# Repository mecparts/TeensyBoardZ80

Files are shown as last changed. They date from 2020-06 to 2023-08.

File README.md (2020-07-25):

# Teensy Board/Z80 - A Teensy4.0 based ZCPR3.3/ZSDOS Z80 computer

The Teensy Board/Z80 is a
[Teensy 4.0](https://www.pjrc.com/store/teensy40.html) computer running a
ZCPR3.3/ZSDOS variant of [RunCPM](https://github.com/MockbaTheBorg/RunCPM).

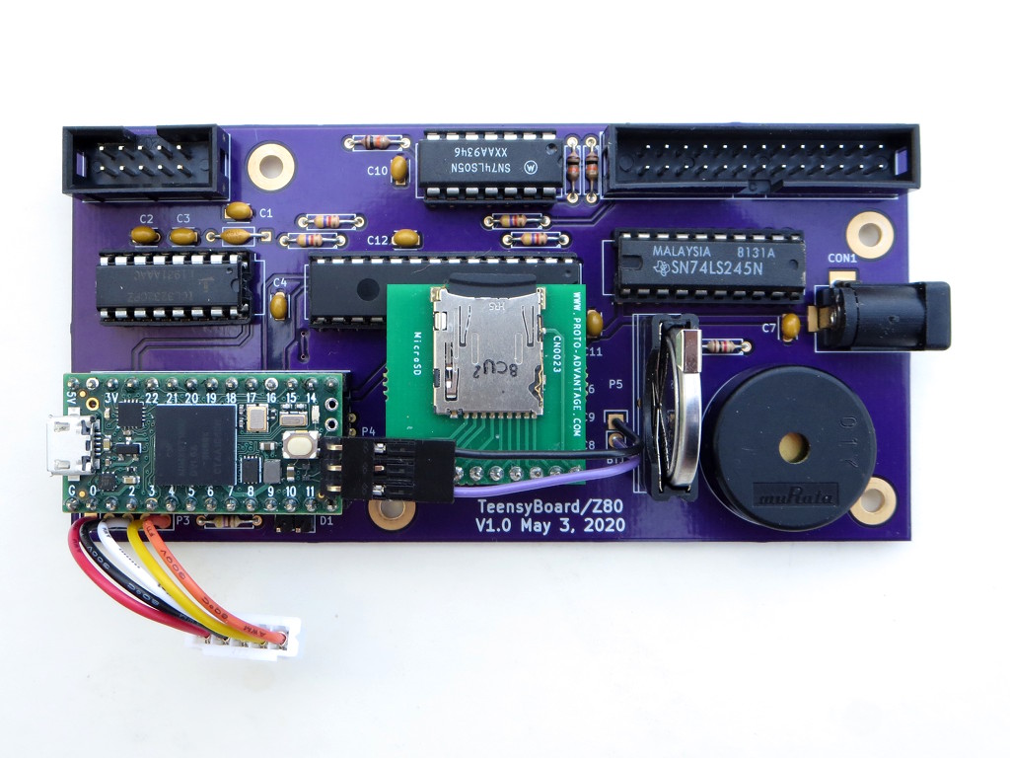
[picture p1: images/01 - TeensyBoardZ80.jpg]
Teensy Board/Z80 The Teensy Board/Z80


Features:
* 100-140MHz equivalent Z80 (RunCPM doesn't emulate cycle times - it just goes *fast*).
* SDIO connected uSD card (about 2.5x faster than SPI) with a standard FAT file system.
* ANSI colour terminal emulator with [GSX](https://github.com/mecparts/pigfx)
graphics support. Runs on a first generation Raspberry Pi, so HDMI video
and USB keyboards are natively supported.
* Battery backed up real time clock.
* Centronics compatible parallel port (DB-25F).
* RS-232 serial port (DE-9M) with RTS/CTS hardware flow control.

## Hardware

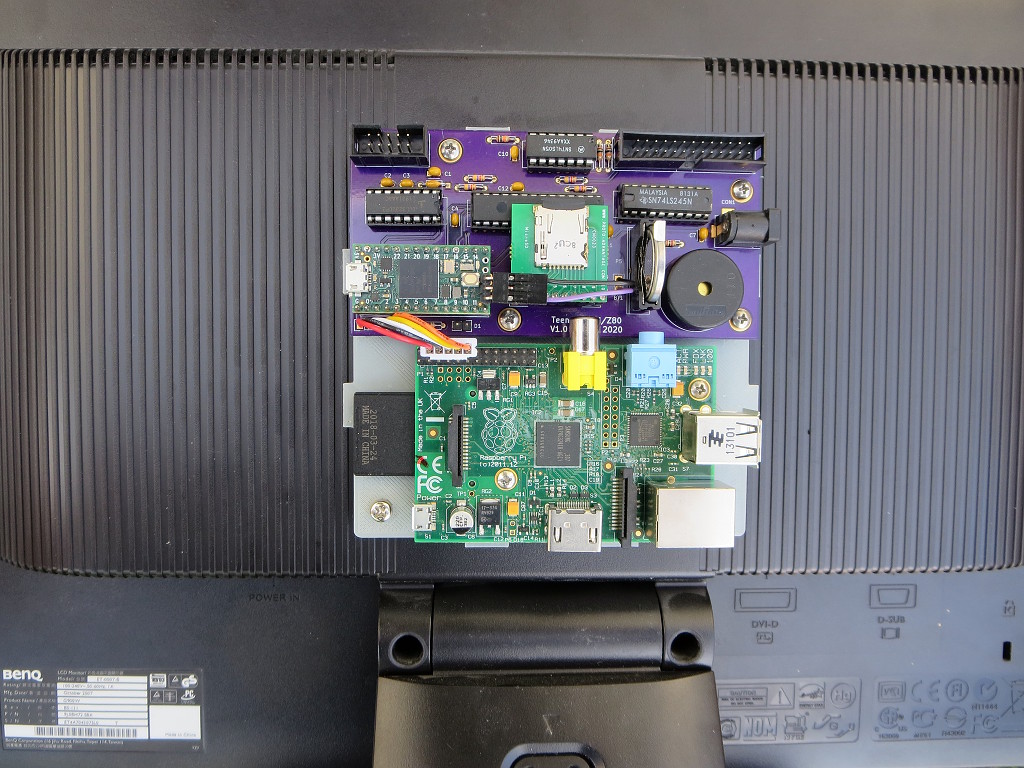
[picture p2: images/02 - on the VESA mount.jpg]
VESA mount The Teensy Board/Z80 and the Raspberry Pi on the VESA mount


The PCB for the Teensy Board/Z80 fits on a VESA mount along with an
original Raspberry Pi 1 B (rev 2). The Pi is the ANSI console used by
the Teensy Board/Z80.

Along with the internal connection to the ANSI terminal, the Teensy Board/Z80
has two vintage I/O ports: an RS-232 port with a DE-9 connector, with
RTS/CTS handshaking, and a Centronics parallel port. The RS-232 port is
the TTY: device in the Teensy Board/Z80's BIOS. The parallel port is,
quite naturally, the LPT: device.

In my setup, the RS-232 port is hooked up to a
[Retro WiFi modem](https://github.com/mecparts/RetroWiFiModem), complete
with Hayes Smartmodem style LED indicators.

The Teensy 4's real time clock is used in ZSDOS to support file timestamps
via the normal ZSDOS calls. A CR2032 coin cell provides the battery back up.

## Case

The Ampro Little Board/Z80 mounted on the bottom of a 5.25" floppy drive.
The Teensy Board/Z80 mounts on a VESA mount on the back on an LCD monitor.

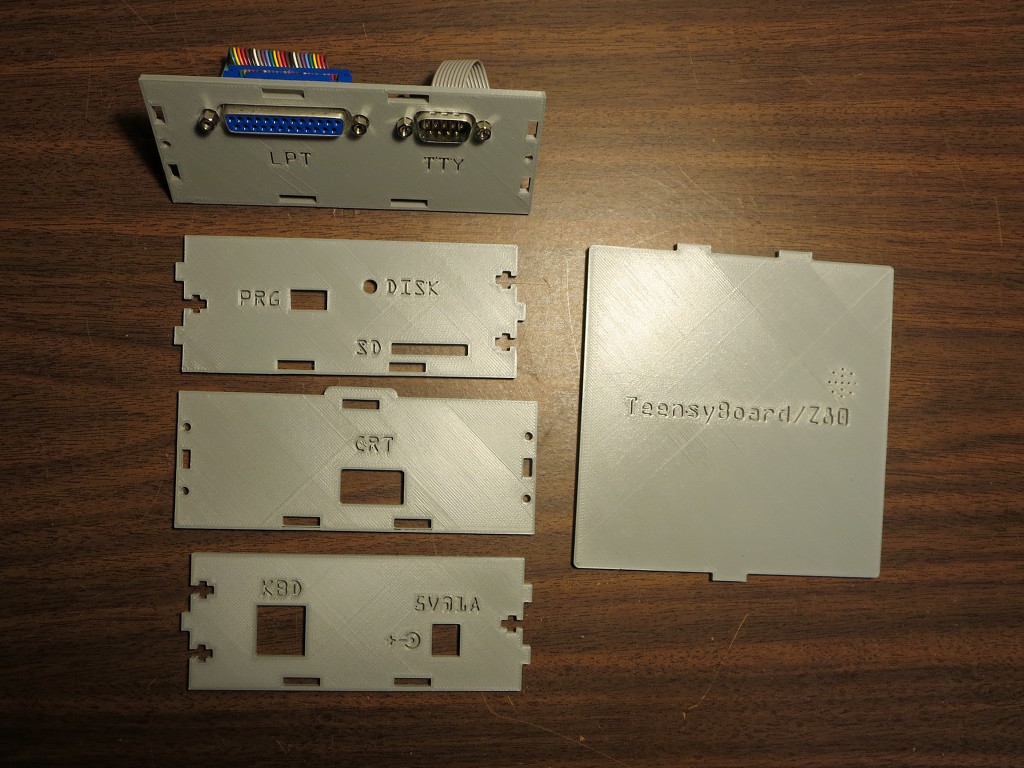
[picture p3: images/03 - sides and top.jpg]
Case bits and pieces The case bits and pieces


The case was designed in OpenSCAD. Although it's 3D printed, it's designed
like a laser cut case, with separate sides, top and bottom. This allowed
a quicker "getting it to fit" cycle than if the bottom and sides had been
printed as one piece; this way, individual sides could by reprinted.

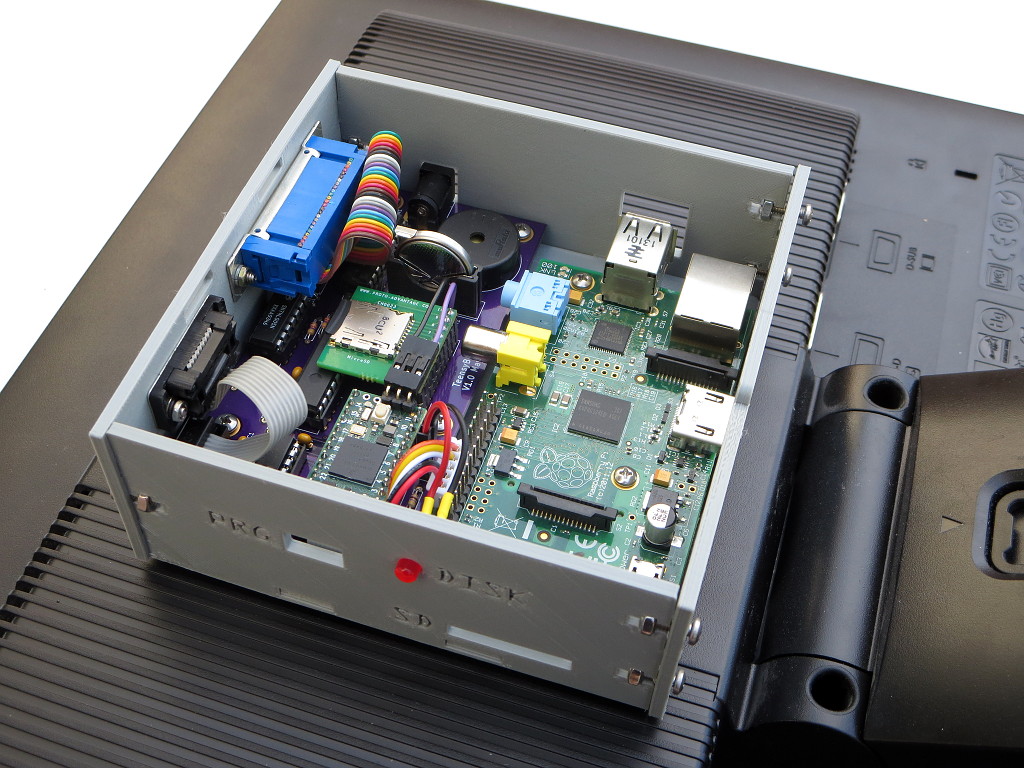
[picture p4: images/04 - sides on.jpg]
Sides on


The base is printed with integrated standoffs. The hole are sized to accept
a #4/40 tap so that no nuts are required. It took a bit of care to get the
holes tapped without snapping the standoffs. Both the Teensy Board PCB and
the Raspberry Pi will take 1/2" 4/40 screws in lieu of the M2.5s normally
specified for the Pi.

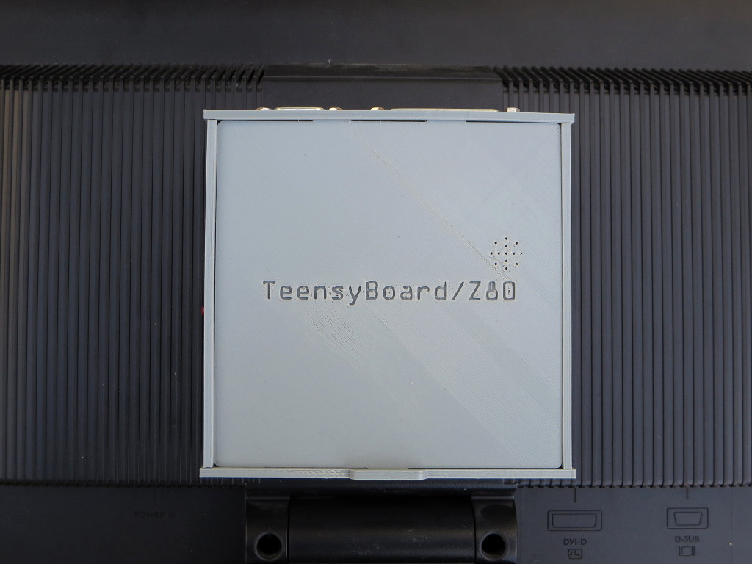
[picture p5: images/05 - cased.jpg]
Completed case The completed case


The sides bolt together with 3/8" #4-40 screws. The filament was plain old
PLA.

## Software

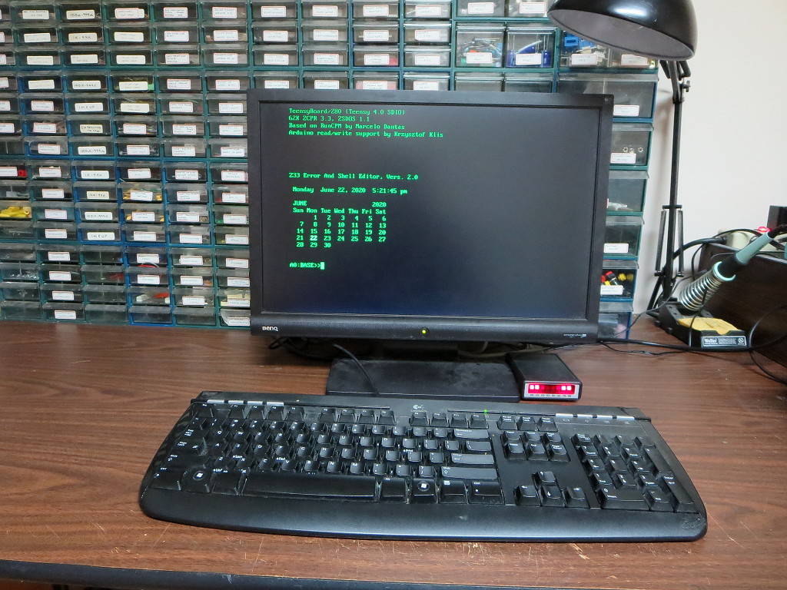
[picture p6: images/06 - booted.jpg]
Booted


When I bought my first Teensy 4.0 last autumn, I'd thought about looking
around for a Z80 emulator written in C and implementing a BIOS in Z80
assembler that would talk to the Teensy hardware... somehow. Luckily, I
came across [RunCPM](https://github.com/MockbaTheBorg/RunCPM) first. It
had already solved the problem of communicating with the Teensy
hardware, and had done it with a FAT file system. I stopped looking! I
had the first system up and running within an hour of getting home with
the Teensy.

Over the winter I helped to get RunCPM's BDOS emulation much closer to
how CP/M operated. I'd done my fair share of BIOS development back in
the day, and had even done some work with a BDOS replacement called
*NovaDOS*, but all that was long ago and far away. But like riding a
bicycle, it all started coming back.

While all that was happening, I was also working on getting ZCPR3.3
working with RunCPM. Then, after adding proper serial and parallel port
support to RunCPM's BDOS and BIOS, I, well, started to get a little
carried away.

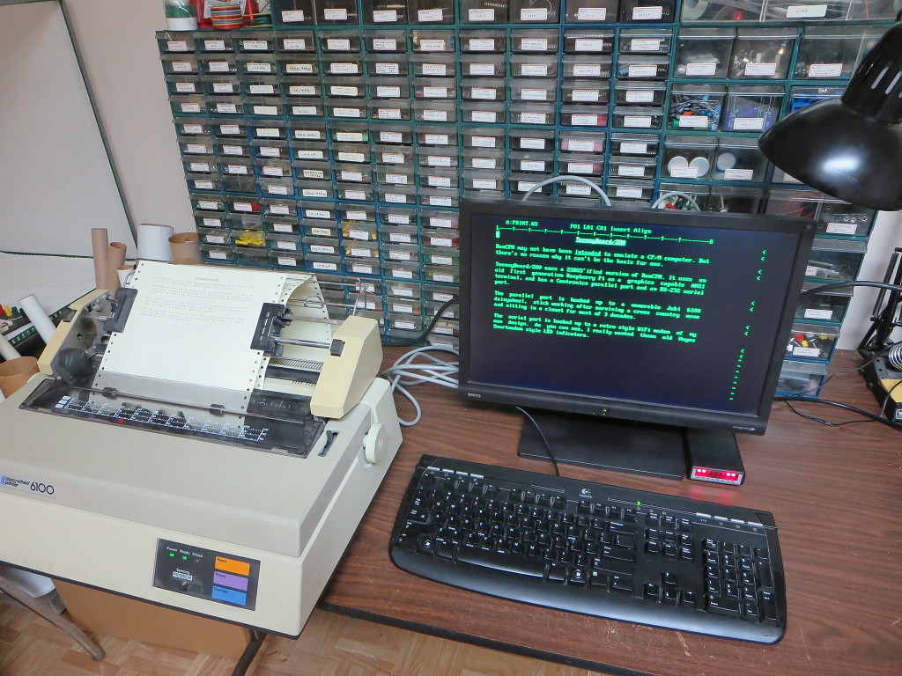
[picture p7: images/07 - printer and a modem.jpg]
Printer and a modem The printer and the modem


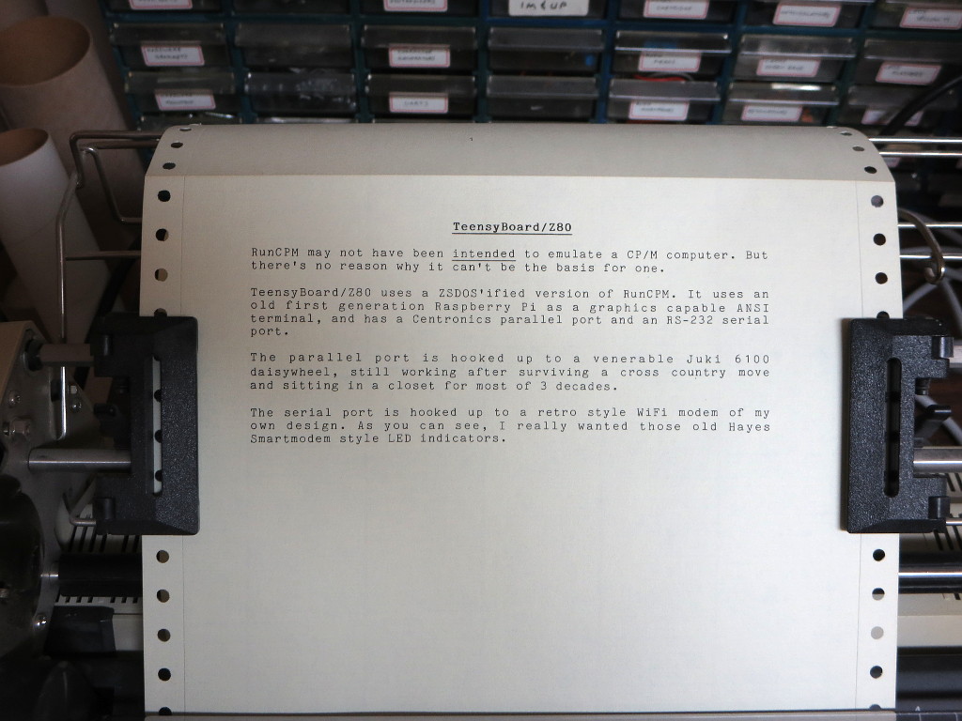
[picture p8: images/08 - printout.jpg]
Yes, it really prints


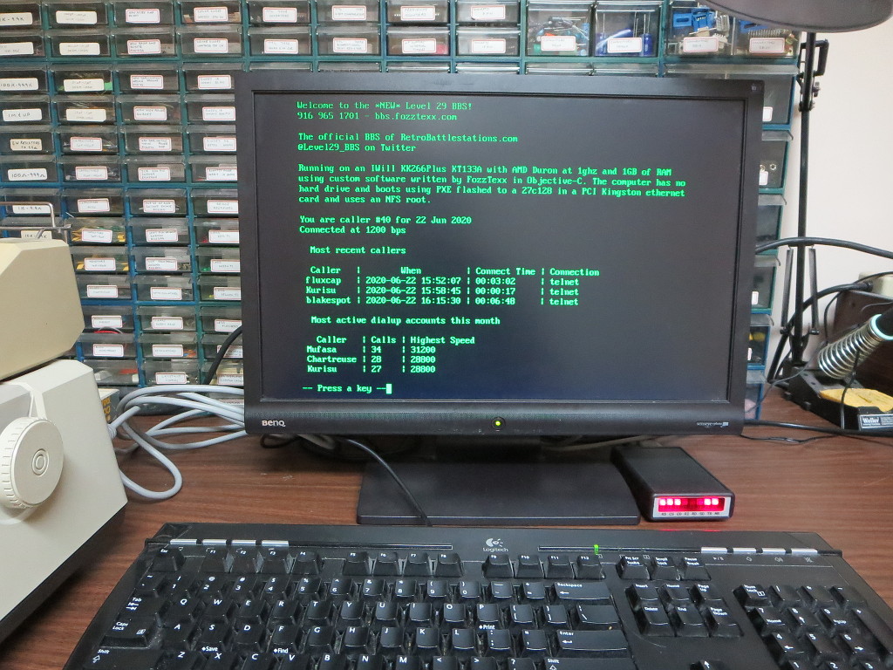
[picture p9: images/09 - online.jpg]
The Teensy Board/Z80 online


A couple of decades of having all those extra cursor and function keys
on my keyboard meant that I kept reaching for them. So I added the
equivalent a ZCPR3 IOP to RunCPM's console input handling. It handled
translating the ANSI style arrow, cursor and function keys to their
WordStar(tm) equivalents. Suddenly, *everything* that used the ZCPR TCAP
knew about all those extra keys. That was incredibly handy. Also, it took
no space at in the Z80's 64K.

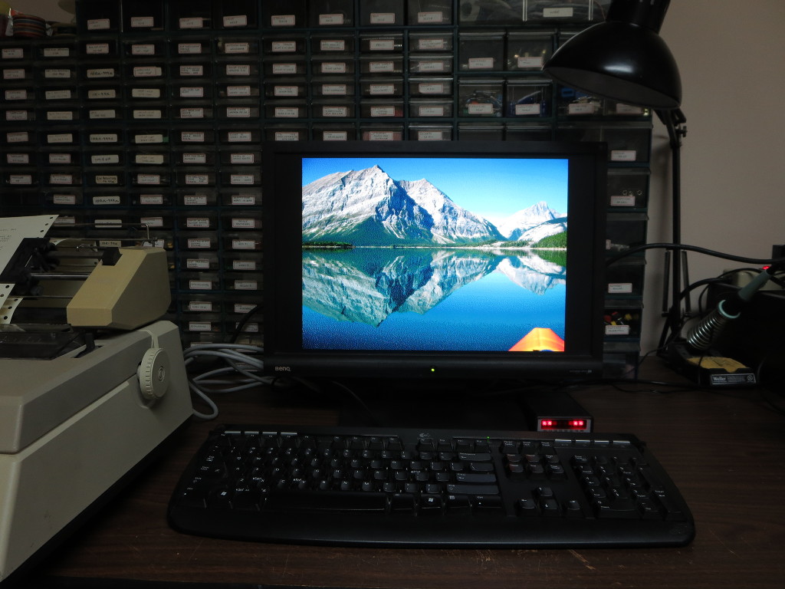
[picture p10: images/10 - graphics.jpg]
And colour graphics too


The Teensy Board/Z80 also implements the GSX (Graphics System Extension)
BDOS call, but without the overhead of having GSX.SYS and a device
driver loaded in the TPA. No more GSX.SYS or GENGRAF.COM! Instead,
everything is handled in the Teensy Board/Z80's BDOS code. Most of the heavy
lifting actually occurs in my modified PiGFX code running on the
Raspberry Pi. Fast as a 115.2K serial connection is, it's way faster
sending the start and end point of a line and letting PiGFX draw it than
it would be to send a "set this pixel" command for each pixel in the
line.

Then, no longer satisfied with what NovaDOS did, I added ZSDOS
capabilities to RunCPM's BDOS. One of the most useful things to get
working was file datestamps. My favourite editor (ZDE16) was already
ZSDOS-aware and capable of maintaining the actual creation date of a
file; and its backup.

## Status

Newest working: ZMP has been re-compiled with Hi Tech C v3.09 and is
working. Baud rates above 19.2K now display properly (as do send/receive
times with at those speeds). Timestamps are working with Ymodem and
Zmodem. Keyboard macros now send CR for ! rather than CR/LF. Automatic
CR on connection has been removed. ! and ~ can be escaped with \ in
keyboard macros so those characters can be sent.

## References

* [RunCPM](https://github.com/MockbaTheBorg/RunCPM): the original
inspiration for this whole project. While RunCPM may not have been
intended to emulate a complete CP/M computer, as the Teensy Board/Z80
shows there's no reason that it can't be expanded into one.
* [PiGFX](https://github.com/mecparts/pigfx): a fork of 
https://github.com/dhansel/pigfx (which is a fork of 
https://github.com/fbergama/pigfx) with all kinds of additions, including
native GSX support.
* [SdFat-beta](https://github.com/mecparts/SdFat-beta): a fork of
https://github.com/greiman/SdFat-beta with support for file attributes.
* [Retro WiFi Modem](https://github.com/mecparts/RetroWiFiModem): a 
WiFi modem in the style of an old Hayes Smartmodem. True RS-232 interface
and LED status indicators.

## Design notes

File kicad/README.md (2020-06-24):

# Teensy Board/Z80 - A Teensy4.0 based ZCPR3.3/ZSDOS Z80 computer

## Schematic

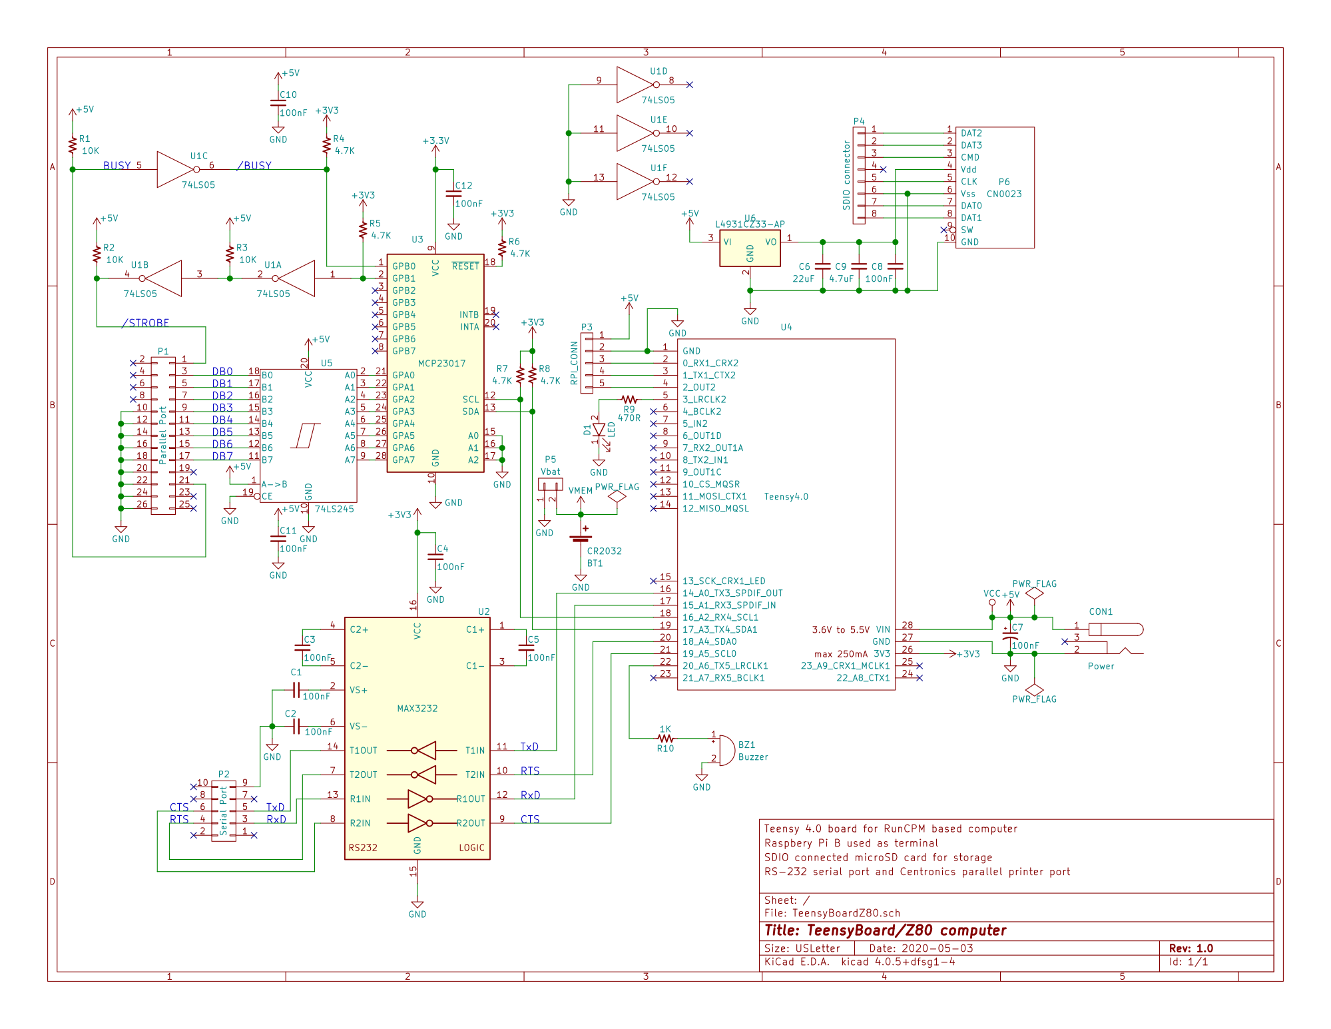
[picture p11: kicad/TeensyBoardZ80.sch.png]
Schematic


I've been asked "why didn't you use a Teensy 4.1 with the built in uSD
holder?" The simple answer is that I designed this before the 4.1 was
announced.

And as to why all the thru hole parts were used when surface mount 
would have allowed either a smaller board or more features in the same
amount of space, this was a "use as many parts that I actually have on
hand" project.

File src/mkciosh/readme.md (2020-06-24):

# Recreating the CIOS.H file

If you have the need to alter the CIOS.H file, here's how I build 
it.

Programs you'll need:

- ZEX
- IF (either resident or transient)
- ZMAC assembler
- Turbo Pascal
- MLOAD

This is done on a running ZCPR system. Use ZEX to run the script 
MKCIOSH.ZEX to build CIOS.H. Then, transfer the CIOS.H file to 
the directory where RunCPM.ino resides (making sure that the 
filename ends up in lower case as cios.h), and rebuild RunCPM.

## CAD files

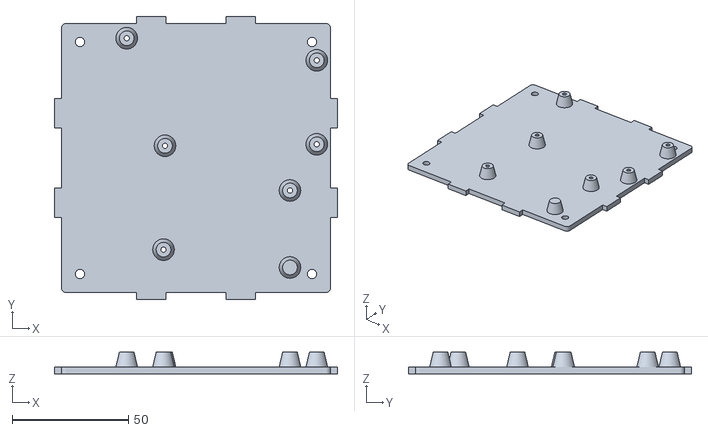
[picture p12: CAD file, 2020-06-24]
openscad/TeensyBoard_VESA_mount_base.stl
122.0 x 122.0 x 9.31

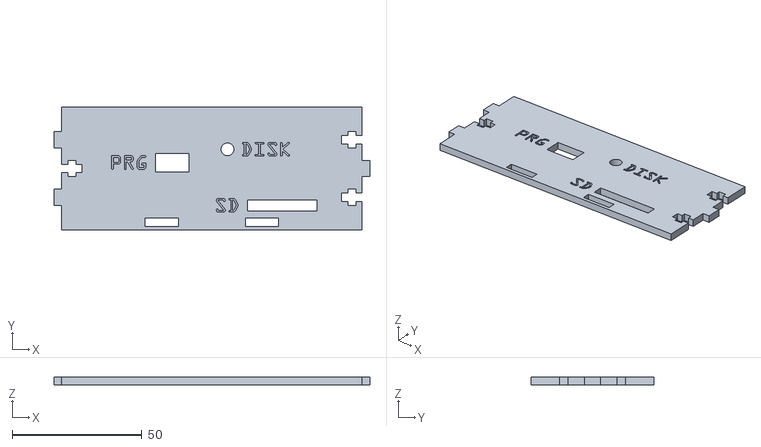
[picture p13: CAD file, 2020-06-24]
openscad/TeensyBoard_VESA_mount_sdcard_side.stl
122.0 x 47.5 x 3.00

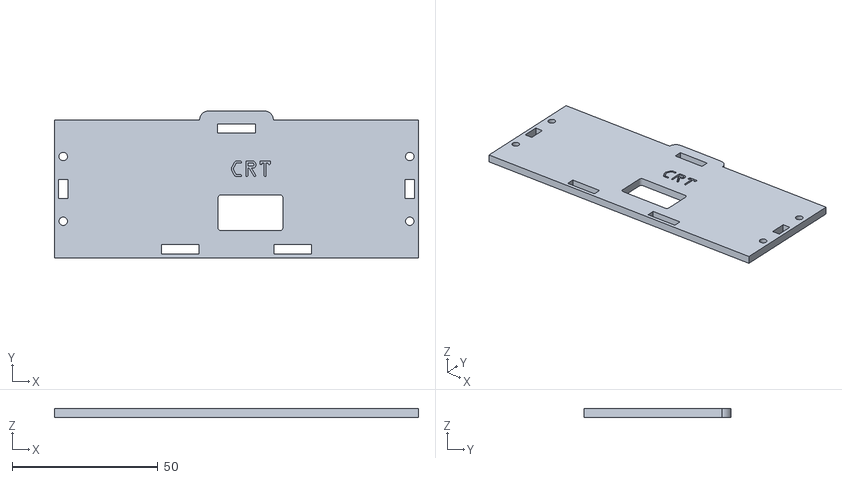
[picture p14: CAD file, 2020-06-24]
openscad/TeensyBoard_VESA_mount_hdmi_end.stl
125.0 x 50.5 x 3.00

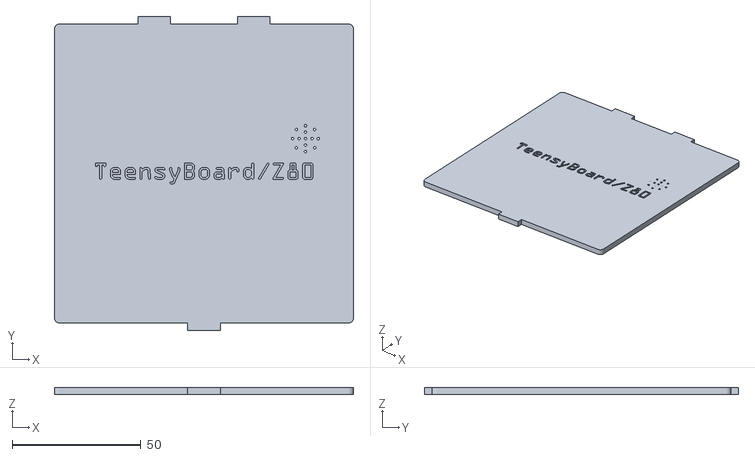
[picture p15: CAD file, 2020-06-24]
openscad/TeensyBoard_VESA_mount_top.stl
116.0 x 121.8 x 2.90

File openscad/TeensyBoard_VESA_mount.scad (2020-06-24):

$fn = 32;
eps = 0.04;
inch = 25.4;

kerf = 0.18;
inset = 0.5;

panel_l = 116;
panel_w = 116;
panel_h = 3.0;
panel_r = 2;

mount_l = 100;
mount_w = 100;
mount_d = 4;

standoff_h = inch/4;
standoff_od = inch/4;
standoff_id = 0.0890 * inch;
fillet_r = 1.5;

htab_l = 0.5 * inch;
htab_h = panel_h;

hslot_l = htab_l + kerf;
hslot_h = htab_h + kerf;

vtab_l = 0.25 * inch;
vtab_h = panel_h;

vslot_l = vtab_l + kerf;
vslot_h = vtab_h + kerf;

side_h = inch * 1.75;

rpi_l = 85;
rpi_w = 56;
rpi_h = 1.4;
rpi_d = 2.9;
rpi_backset = 12;
rpi_xy = [panel_l - rpi_backset - rpi_l - inset, inset, 0];
rpi_xy1 = [25.5, 18,0];
rpi_xy2 = [rpi_l - 5, rpi_w - 12.5, 0];
rpi_xy3 = [rpi_l - 5, 13/32 * inch, 0];

hdmi_xc = 36.8 + 15/2;
hdmi_yc = panel_h + standoff_h + rpi_h + 0.256/2*inch;
hdmi_l = 0.798 * inch + 2;
hdmi_h = 0.405 * inch + 2;

usb_l = 0.635*inch + 1;
usb_h = 0.670*inch + 1;
usb_xc = inset + 2 + 15.9 +6.1 + 13.1/2;
usb_yc = panel_h + standoff_h + rpi_h + 17/2;

sd_socket_l = 1.115 * inch;
sd_l = (0.060 * 2 + 0.943) * inch;
sd_h = 0.136 * inch + rpi_h / 2;
sd_x = panel_w - inset - 0.612*inch - sd_socket_l;
sd_y = panel_h + standoff_h + rpi_h / 2 - sd_h;

tb_l = 4.25 * inch;
tb_w = 2.25 * inch;
tb_xy = [inset, panel_w - inset, 0];
tb_xy1 = [27.635, -5.88, 0];
tb_xy2 = [44.145, -52.235, 0];
tb_xy3 = [109.55, -51.6, 0];
tb_xy4 = [109.55, -15.405, 0];
tb_d = 3.2;

barrel_w = 0.354*inch;
barrel_h = 0.428*inch;
barrel_xc = panel_w - inset -26.835;
barrel_yc = panel_h + standoff_h + inch/16 + barrel_h/2;

teensy_usb_l = 0.474 * inch + 1;
teensy_usb_h = 0.243 * inch + 1;
teensy_usb_xc = 42.71;
teensy_usb_yc = panel_h + standoff_h + inch/16 + 13.5;

module base() {
   difference() {
      union() {
         linear_extrude(height=panel_h) {
            hull() {
               translate([panel_r,panel_r,0]) {
                  circle(r=panel_r);
               }
               translate([panel_l-panel_r,panel_r,0]) {
                  circle(r=panel_r);
               }
               translate([panel_l-panel_r,panel_w-panel_r,0]) {
                  circle(r=panel_r);
               }
               translate([panel_r,panel_w-panel_r,0]) {
                  circle(r=panel_r);
               }
            }
            
            translate([panel_l/3, -htab_h/2 + eps, 0]) {
               square([htab_l,htab_h+eps], center = true);
            }
            translate([2*panel_l/3,-htab_h/2 + eps,0]) {
               square([htab_l,htab_h+eps], center = true);
            }

            translate([panel_l/3, panel_w + htab_h/2 - eps, 0]) {
               square([htab_l, htab_h + eps], center = true);
            }
            translate([2*panel_l/3, panel_w + htab_h/2 - eps, 0]) {
               square([htab_l, htab_h + eps], center = true);
            }

            translate([-htab_h/2 + eps,panel_w/3, 0]) {
               square([htab_h + eps, htab_l], center = true);
            }
            translate([-htab_h/2 + eps, 2*panel_w/3, 0]) {
               square([htab_h+eps,htab_l], center = true);
            }
            
            translate([panel_l + htab_h/2 - eps, panel_w/3, 0]) {
               square([htab_h + eps, htab_l], center = true);
            }
            translate([panel_l + htab_h/2 - eps, 2*panel_w/3, 0]) {
               square([htab_h + eps, htab_l], center = true);
            }
         }
         translate([0, 0, panel_h - eps]) {
            translate(rpi_xy) {
               translate(rpi_xy1) {
                  cylinder(h=standoff_h,d2=standoff_od,d1=standoff_od+2*fillet_r);
               }
               translate(rpi_xy2) {
                  cylinder(h=standoff_h,d2=standoff_od,d1=standoff_od+2*fillet_r);
               }
               translate(rpi_xy3) {
                  cylinder(h=standoff_h,d2=standoff_od,d1=standoff_od+2*fillet_r);
               }
            }
            translate(tb_xy) {
               translate(tb_xy1) {
                  cylinder(h=standoff_h,d2=standoff_od,d1=standoff_od+2*fillet_r);
               }
               translate(tb_xy2) {
                  cylinder(h=standoff_h,d2=standoff_od,d1=standoff_od+2*fillet_r);
               }
               translate(tb_xy3) {
                  cylinder(h=standoff_h,d2=standoff_od,d1=standoff_od+2*fillet_r);
               }
               translate(tb_xy4) {
                  cylinder(h=standoff_h,d2=standoff_od,d1=standoff_od+2*fillet_r);
               }
            }
         }
      }
      translate([0, 0, -eps]) {
         translate([(panel_l-mount_l)/2, (panel_w-mount_w)/2, 0]) {
            cylinder(h=panel_h+2*eps,d=mount_d);
         }
         translate([(panel_l+mount_l)/2, (panel_w-mount_w)/2, 0]) {
            cylinder(h=panel_h+2*eps,d=mount_d);
         }
         translate([(panel_l-mount_l)/2, (panel_w+mount_w)/2, 0]) {
            cylinder(h=panel_h+2*eps,d=mount_d);
         }
         translate([(panel_l+mount_l)/2, (panel_w+mount_w)/2, 0]) {
            cylinder(h=panel_h+2*eps,d=mount_d);
         }
         translate(rpi_xy) {
            translate(rpi_xy1) {
               cylinder(h=(panel_h+standoff_h)+2*eps,d=standoff_id);
            }
            translate(rpi_xy2) {
               cylinder(h=(panel_h+standoff_h)+2*eps,d=standoff_id);
            }
         }
         translate(tb_xy) {
            translate(tb_xy1) {
               cylinder(h=(panel_h+standoff_h)+2*eps,d=standoff_id);
            }
            translate(tb_xy2) {
               cylinder(h=(panel_h+standoff_h)+2*eps,d=standoff_id);
            }
            translate(tb_xy3) {
               cylinder(h=(panel_h+standoff_h)+2*eps,d=standoff_id);
            }
            translate(tb_xy4) {
               cylinder(h=(panel_h+standoff_h)+2*eps,d=standoff_id);
            }
         }
      }
   }
}

module top() {
   difference() {
      linear_extrude(height=panel_h) {
         union() {
            hull() {
               translate([panel_r,panel_r,0]) {
                  circle(r=panel_r);
               }
               translate([panel_l-panel_r,panel_r,0]) {
                  circle(r=panel_r);
               }
               translate([panel_l-panel_r,panel_w-panel_r,0]) {
                  circle(r=panel_r);
               }
               translate([panel_r,panel_w-panel_r,0]) {
                  circle(r=panel_r);
               }
            }
            
            translate([panel_l/3, panel_w + htab_h/2 - eps, 0]) {
               square([htab_l,htab_h+eps], center = true);
            }
            translate([2*panel_l/3,panel_w + htab_h/2 - eps,0]) {
               square([htab_l,htab_h+eps], center = true);
            }

            translate([panel_l/2, -htab_h/2 + eps, 0]) {
               square([htab_l, htab_h + eps], center = true);
            }
         }
      }
      translate([panel_l/2, panel_w/2, panel_h/2] ) {
         linear_extrude(height=panel_h/2+eps) {
            text("TeensyBoard/Z80", font="OCR A Extended", halign="center", valign="center", size = 7);
         }
      }
      translate([0, 0, -eps]) {
         translate([inset+96.85, panel_w-inset-43.98, 0]) {
            cylinder(h=panel_h+2*eps,d=1);
         }
         translate([inset+96.85-2.5, panel_w-inset-43.98, 0]) {
            cylinder(h=panel_h+2*eps,d=1);
         }
         translate([inset+96.85+2.55, panel_w-inset-43.98, 0]) {
            cylinder(h=panel_h+2*eps,d=1);
         }
         translate([inset+96.85, panel_w-inset-43.98-2.5, 0]) {
            cylinder(h=panel_h+2*eps,d=1);
         }
         translate([inset+96.85, panel_w-inset-43.98+2.5, 0]) {
            cylinder(h=panel_h+2*eps,d=1);
         }
         translate([inset+96.85-5, panel_w-inset-43.98, 0]) {
            cylinder(h=panel_h+2*eps,d=1);
         }
         translate([inset+96.85+5, panel_w-inset-43.98, 0]) {
            cylinder(h=panel_h+2*eps,d=1);
         }
         translate([inset+96.85, panel_w-inset-43.98-5, 0]) {
            cylinder(h=panel_h+2*eps,d=1);
         }
         translate([inset+96.85, panel_w-inset-43.98+5, 0]) {
            cylinder(h=panel_h+2*eps,d=1);
         }

         translate([inset+96.85-5*0.707, panel_w-inset-43.98-5*0.707, 0]) {
            cylinder(h=panel_h+2*eps,d=1);
         }
         translate([inset+96.85+5*0.707, panel_w-inset-43.98-5*0.707, 0]) {
            cylinder(h=panel_h+2*eps,d=1);
         }
         translate([inset+96.85-5*0.707, panel_w-inset-43.98+5*0.707, 0]) {
            cylinder(h=panel_h+2*eps,d=1);
         }
         translate([inset+96.85+5*0.707, panel_w-inset-43.98+5*0.707, 0]) {
            cylinder(h=panel_h+2*eps,d=1);
         }
      }
   }
}
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

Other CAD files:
openscad/TeensyBoard_VESA_mount_port_end.stl
openscad/TeensyBoard_VESA_mount_usb_side.stl

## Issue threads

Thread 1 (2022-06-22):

Problems using latest SD-FAT (beta)

homebrew-z80, 2022-06-22:
It seems that sdfat-beta has progressed since the latest date of this teensyboardz80 source and it is unclear how to get a clean arduino build. Please clarify which build of sdfat  is required and whether the ".h" include should be for sdfat.h or sdfat-beta.h in teensyboardz80.ino

I am getting this build error :
In file included from C:\Users\rwdea\Downloads\TeensyBoardZ80-master\TeensyBoardZ80-master\TeensyBoardZ80\TeensyBoardZ80.ino:4:0:
C:\Users\rwdea\Documents\Arduino\libraries\SdFat-beta-2.1.4-beta.3\src/SdFat.h:452:2: warning: #warning File not defined because __has_include(FS.h) [-Wcpp]
 #warning File not defined because __has_include(FS.h)
  ^
In file included from C:\Users\rwdea\Downloads\TeensyBoardZ80-master\TeensyBoardZ80-master\TeensyBoardZ80\TeensyBoardZ80.ino:71:0:
abstraction_arduino.h: In function 'bool _RamLoad(char*, uint16)':
abstraction_arduino.h:15: error: 'File' was not declared in this scope
  File f;
  ^
abstraction_arduino.h:18: error: 'f' was not declared in this scope
  if (f = SD.open(filename, FILE_READ)) {

mecparts, 2022-06-23:
As noted in the [References section at the at the readme](https://github.com/mecparts/TeensyBoardZ80#references), it's [my fork of SdFat-beta](https://github.com/mecparts/SdFat-beta) that's used.

homebrew-z80, 2022-06-23:
Thanks,  I had missed that, and hoped it worked with more recent. I will
set that up and work with it.

Richard

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

Closed 2022-07-05.

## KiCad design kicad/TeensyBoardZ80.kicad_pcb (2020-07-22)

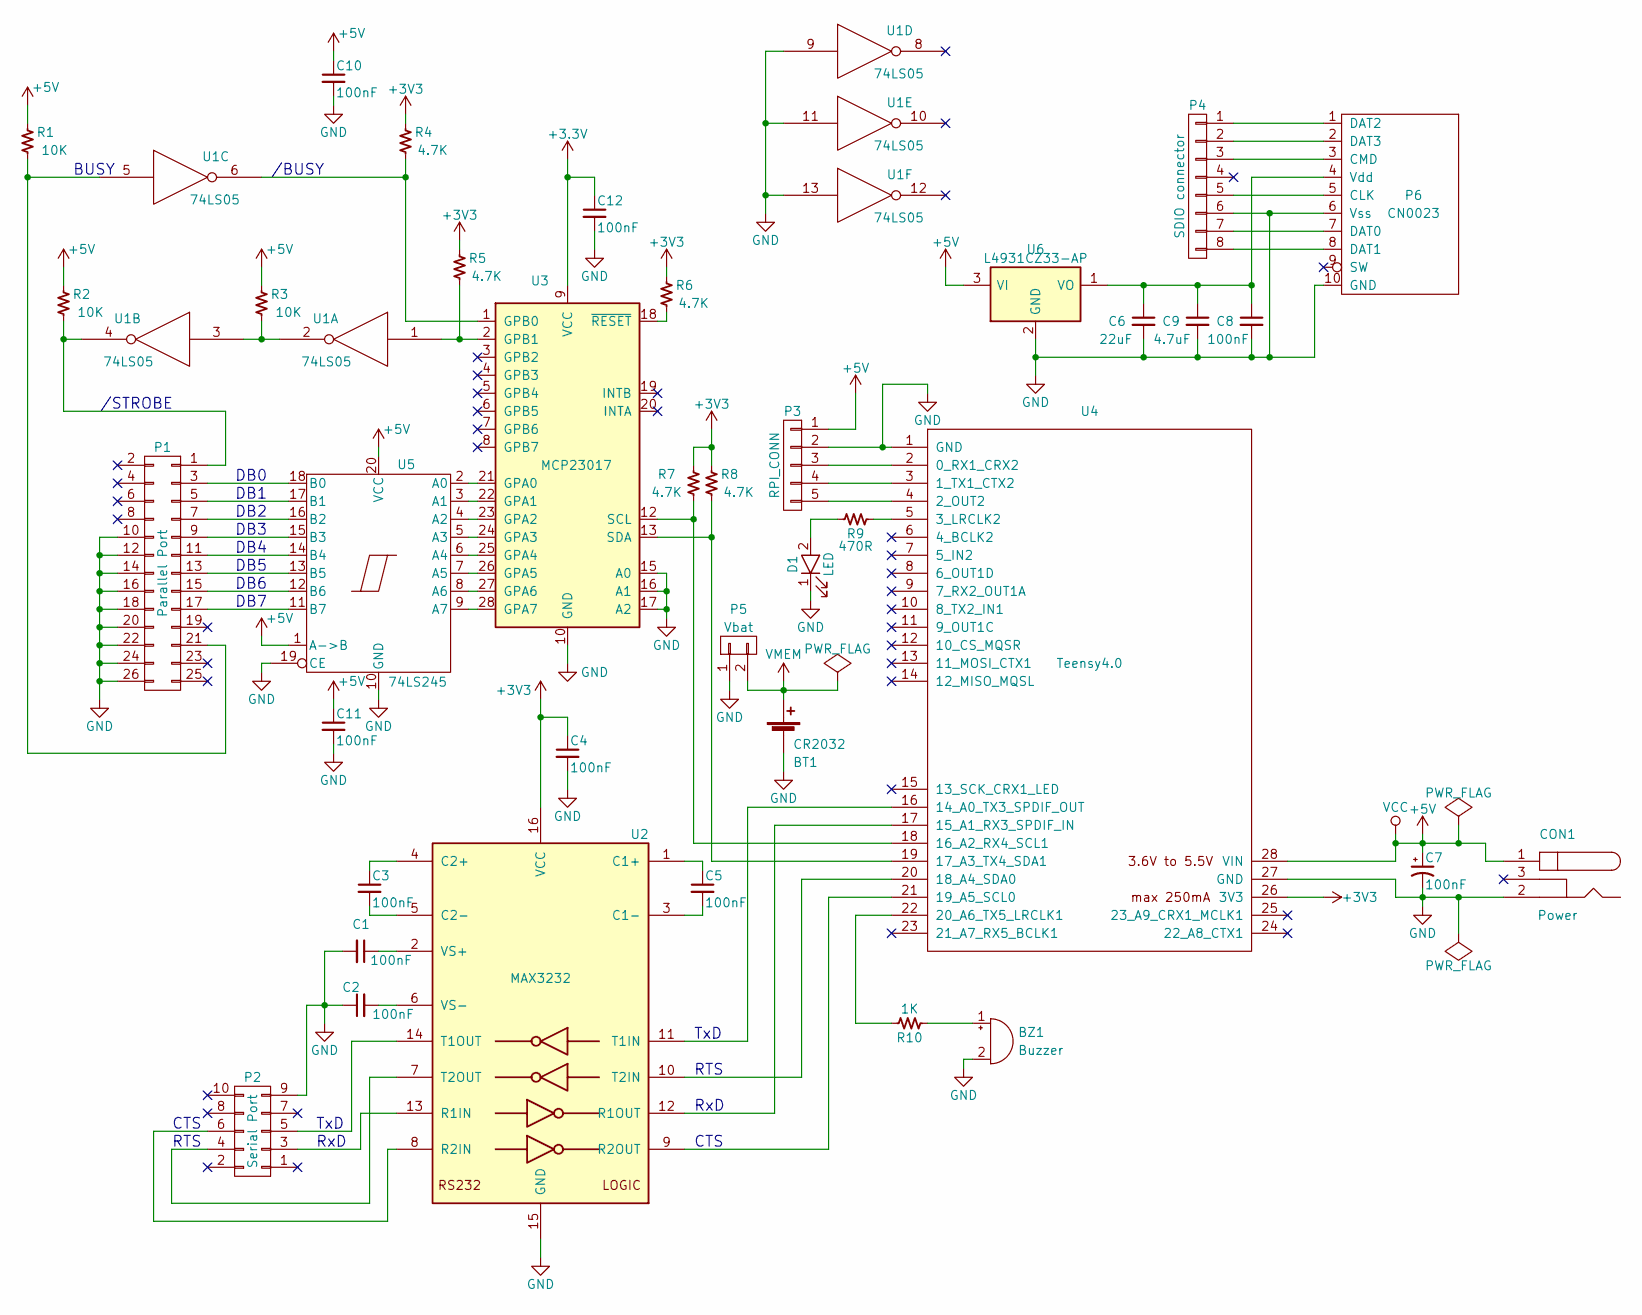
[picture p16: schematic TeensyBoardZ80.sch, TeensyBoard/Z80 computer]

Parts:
BT1: CR2032; CR2032V; DigiKey PN BS-5-ND
BZ1: Buzzer; PKM22EPP; DigiKey PN 490-7031-ND
C1, C2, C3, C4, C7, C8, C10, C11, C12: 100nF; C_Disc_D3_P2.5; DigiKey PN 399-9843-ND
C5: 100nF; C_Axial_D2.5_L4.3_P7.5; DigiKey PN 399-9843-ND
C6: 22uF; C_Disc_D3_P2.5; DigiKey PN 399-3574-ND
C9: 4.7uF; C_Disc_D3_P2.5; DigiKey PN 399-3543-ND
CON1: Power; BARREL_JACK; DigiKey PN 839-54-00166-ND
D1: LED; Pin_Header_Straight_1x02
P1: Parallel Port; IDC_Header_Straight_26pins; DigiKey PN 377-2269-ND
P2: Serial Port; IDC_Header_Straight_10pins; DigiKey PN 296-1589-5-ND
P3: RPI_CONN; Pin_Header_Straight_1x05
P4: SDIO connector; HLW8R-2C7LF; DigiKey PN HLW8R-2C7LF
P5: Vbat; Pin_Header_Straight_1x02
P6: CN0023; DigiKey PN CN0023-ND
R1, R2, R3: 10K; R3; DigiKey PN CF18JT10K0CT-ND
R4, R5, R6, R7, R8: 4.7K; R3; DigiKey PN CF18JT4K70CT-ND
R9: 470R; R3; DigiKey PN CF18JT470R
R10: 1K; R3; DigiKey PN CF18JT1K00CT-ND
U1: 74LS05; DIP-14_W7.62mm_LongPads; DigiKey PN 296-1631-5-ND
U2: MAX3232; DIP-16_W7.62mm; DigiKey PN ICL3232CPZ-ND
U3: MCP23017; DIP-28_W7.62mm_LongPads
U4: Teensy4.0; Teensy40; DigiKey PN 1568-DEV-15583-ND
U5: 74LS245; DIP-20_W7.62mm_LongPads
U6: L4931CZ33-AP; TO-92_Inline_Wide; DigiKey PN 497-7246-1-ND

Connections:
+5V: C7.1, C10.1, C11.1, CON1.1, P3.1, R1.2, R2.2, R3.2, U1.14 (VCC), U4.28 (VIN), U5.1 (A->B), U5.20 (VCC), U6.3 (VI)
GND: BT1.2 (-), BZ1.2 (+), C1.2, C2.1, C4.2, C6.2, C7.2, C8.2, C9.2, C10.2, C11.2, C12.2, CON1.2, D1.1 (K), P1.10, P1.12, P1.14, P1.16, P1.18, P1.20, P1.22, P1.24, P1.26, P2.9, P3.2, P4.6, P5.1, P6.6 (Vss), P6.10 (GND), U1.7 (GND), U1.9, U1.11, U1.13, U2.15 (GND), U3.10 (GND), U3.15 (A0), U3.16 (A1), U3.17 (A2), U4.1 (GND), U4.27 (GND), U5.10 (GND), U5.19 (CE), U6.2 (GND)
unnamed: BZ1.1 (-), R10.1
unnamed: C1.1, U2.2 (VS+)
unnamed: C2.2, U2.6 (VS-)
unnamed: C3.1, U2.4 (C2+)
unnamed: C3.2, U2.5 (C2-)
unnamed: C5.1, U2.1 (C1+)
unnamed: C5.2, U2.3 (C1-)
unnamed: C6.1, C8.1, C9.1, P6.4 (Vdd), U6.1 (VO)
unnamed: D1.2 (A), R9.2
unnamed: P1.1, R2.1, U1.4
unnamed: P1.3, U5.18 (B0)
unnamed: P1.5, U5.17 (B1)
unnamed: P1.7, U5.16 (B2)
unnamed: P1.9, U5.15 (B3)
unnamed: P1.11, U5.14 (B4)
unnamed: P1.13, U5.13 (B5)
unnamed: P1.15, U5.12 (B6)
unnamed: P1.17, U5.11 (B7)
unnamed: P1.21, R1.1, U1.5
unnamed: P2.3, U2.13 (R1IN)
unnamed: P2.4, U2.7 (T2OUT)
unnamed: P2.5, U2.14 (T1OUT)
unnamed: P2.6, U2.8 (R2IN)
unnamed: P3.3, U4.2 (0_RX1_CRX2)
unnamed: P3.4, U4.3 (1_TX1_CTX2)
unnamed: P3.5, U4.4 (2_OUT2)
unnamed: P4.1, P6.1 (DAT2)
unnamed: P4.2, P6.2 (DAT3)
unnamed: P4.3, P6.3 (CMD)
unnamed: P4.5, P6.5 (CLK)
unnamed: P4.7, P6.7 (DAT0)
unnamed: P4.8, P6.8 (DAT1)
unnamed: R3.1, U1.2, U1.3
unnamed: R4.1, U1.6, U3.1 (GPB0)
unnamed: R5.1, U1.1, U3.2 (GPB1)
unnamed: R6.1, U3.18 (~RESET)
unnamed: R7.1, U3.12 (SCL), U4.18 (16_A2_RX4_SCL1)
unnamed: R8.1, U3.13 (SDA), U4.19 (17_A3_TX4_SDA1)
unnamed: R9.1, U4.5 (3_LRCLK2)
unnamed: R10.2, U4.22 (20_A6_TX5_LRCLK1)
unnamed: U2.9 (R2OUT), U4.21 (19_A5_SCL0)
unnamed: U2.10 (T2IN), U4.20 (18_A4_SDA0)
unnamed: U2.11 (T1IN), U4.16 (14_A0_TX3_SPDIF_OUT)
unnamed: U2.12 (R1OUT), U4.17 (15_A1_RX3_SPDIF_IN)
unnamed: U3.21 (GPA0), U5.2 (A0)
unnamed: U3.22 (GPA1), U5.3 (A1)
unnamed: U3.23 (GPA2), U5.4 (A2)
unnamed: U3.24 (GPA3), U5.5 (A3)
unnamed: U3.25 (GPA4), U5.6 (A4)
unnamed: U3.26 (GPA5), U5.7 (A5)
unnamed: U3.27 (GPA6), U5.8 (A6)
unnamed: U3.28 (GPA7), U5.9 (A7)
VMEM: BT1.1 (+), P5.2

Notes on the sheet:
BUSY
/BUSY
TxD
RTS
RxD
CTS
/STROBE
DB7
DB6
DB5
DB4
DB3
DB2
DB1
DB0

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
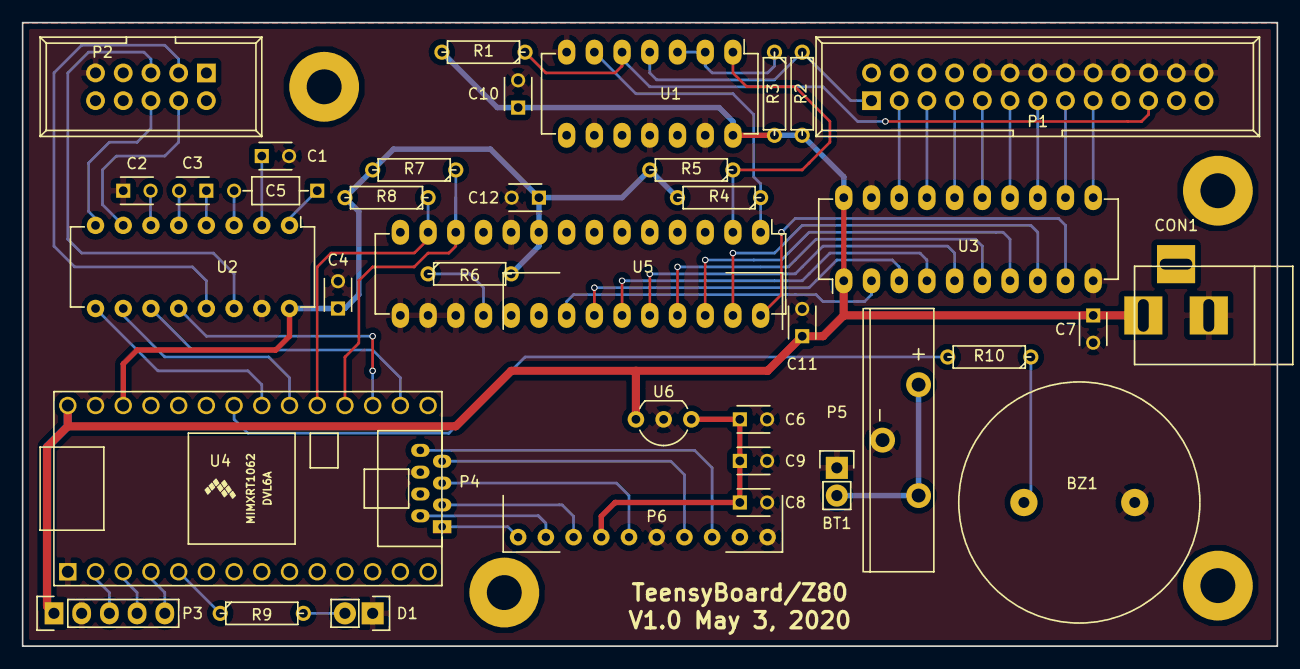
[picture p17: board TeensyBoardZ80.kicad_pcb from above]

Board: 2 copper layers, 115.0 x 57.2 mm, 38 parts (0 on the bottom side), 56 nets.

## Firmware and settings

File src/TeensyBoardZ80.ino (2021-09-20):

#include "globals.h"

#include <SPI.h>
#include <SdFat-beta.h>  // One SD library to rule them all - Greinman SdFat from Library Manager
#include <Wire.h>

SdFat SD;
#define USE_SDIO
#if defined USE_SDIO
#define SDINIT SdioConfig(FIFO_SDIO)
#define SD_IFC "SDIO"
#else
#define SDINIT 10
#define SD_IFC "SPI"
#endif
#define LED 3
#define LEDinv 0
#if defined ARDUINO_TEENSY41
#define BOARD "Teensy 4.1"
#elif defined ARDUINO_TEENSY40
#define BOARD "Teensy 4.0"
#else
#define BOARD "Unknown board"
#endif

#define MODEMPORT Serial3
#define MODEMSPD 9600
#define MODEMRTS 18
#define MODEMCTS 19
#define MODEMCTSREAD 21
#define MODEMDATABITS 8
#define MODEMSTOPBITS 1

uint32 modemSpeed = MODEMSPD;

#define LPT_PORT		Wire1
#define LPT_ADDR		0x20		// MCP23017 I2C address

// MCP23017 registers
#define LPT_IODIRA	0x00
#define LPT_IODIRB	0x01
#define LPT_IOCON		0x0A
#define LPT_GPPUB		0x0D		// pull ups for control port
#define LPT_GPIOA		0x12		// LPT data port
#define LPT_GPIOB		0x13		// LPT status/control port

#define LPT_CONFIG	0x20		// SEQOP
#define LPT_BUSY		0x01		// /BUSY on GPIOB.1
#define LPT_STROBE	0x02		// /STROBE out on GPIOB.2

#define BEEPER 20

#define USE_GSX
#define PiGFX
//#define TFT
//#define ST7735
//#define ILI9341

// Delays for LED blinking
#define sDELAY 100
#define DELAY 200

// Serial (terminal) port speed
#define TERMINALPORT Serial1
#define SERIALSPD 115200
#define STARTUP_DELAY   3000
#define TERMINALRTS 2

#define USR1PORT Serial

#include "abstraction_arduino.h"

#include "ram.h"
#include "logical_io.h"
#include "cpu.h"
#include "disk.h"
#include "host.h"
#ifdef USE_GSX
#include "gsx.h"
#endif
#include "cpm.h"

void setup(void) {
   int32 startup_delay = STARTUP_DELAY;
   
	pinMode(LED, OUTPUT);
	digitalWrite(LED, LOW);

	TERMINALPORT.begin(SERIALSPD);
   pinMode(TERMINALRTS, INPUT_PULLDOWN);
	while (!TERMINALPORT) {	// Wait until serial is connected
		digitalWrite(LED, HIGH^LEDinv);
		delay(sDELAY);
		digitalWrite(LED, LOW^LEDinv);
		delay(sDELAY);
	}
#if defined MODEMPORT
	MODEMPORT.begin(MODEMSPD);
	if (!MODEMPORT.attachRts(MODEMRTS)) {
		TERMINALPORT.println("Could not attach RTS.");
		return;
	}
	if (!MODEMPORT.attachCts(MODEMCTS)) {
		TERMINALPORT.println("Could not attach CTS.");
		return;
	}
	pinMode(MODEMCTSREAD, INPUT);
#endif

#ifdef LPT_PORT
	LPT_PORT.begin();
	_writeI2Cregister(LPT_IOCON, LPT_CONFIG);	// IOCON.SEQOP
	_writeI2Cregister(LPT_GPPUB, LPT_BUSY);	// enable /BUSY pull up resistor
	_writeI2Cregister(LPT_IODIRA, 0x00);		// data port all outputs
	_writeI2Cregister(LPT_GPIOB, LPT_STROBE);	// make sure /STROBE starts inactive
	_writeI2Cregister(LPT_IODIRB, LPT_BUSY);	// /BUSY is an input; all others out
#endif
		
   while (startup_delay > 0) {
		digitalWrite(LED, HIGH^LEDinv);
		delay(sDELAY);
      startup_delay -= sDELAY;
		digitalWrite(LED, LOW^LEDinv);
		delay(sDELAY);
      startup_delay -= sDELAY;
	}
   
#ifdef DEBUGLOG
	_sys_deletefile((uint8 *)LogName);
#endif

	for( unsigned a=0; a<MEMSIZE; ++a ) {
		_RamWrite(a, 0);
	}
	_RamWrite(IOBYTE, 0b10000001);	// CON:=CRT, RDR:=TTY:, PUN:=TTY, LST:=LPT:
	_clrscr();
	_putcon('\a');
	_puts("TeensyBoard/Z80 (");
	_puts(BOARD);
	_putcon(' ');
	_puts(SD_IFC);
	_puts(")\r\n");
	_puts(STR(CPMSIZE));
	_puts("K ZCPR ");
	_putcon(Z3REV / 10 + '0');
	_putcon('.');
	_putcon(Z3REV % 10 + '0');
	_puts(", ZSDOS 1.1\r\n");
	_puts("Based on RunCPM by Marcelo Dantas\r\n");
	_puts("Arduino read/write support by Krzysztof Klis\r\n");
   _puts("\x1b[#1w");   // Set PiGFX keyboard into Wordstar mode

	if (SD.begin(SDINIT)) {
#if defined USE_GSX
		gsx.begin();
#endif

		if (VersionCCP >= 0x10 || SD.exists(CCPname)) {
			while (true) {
				_PatchCPM();
				Status = RUNNING;
				if (!_RamLoad((char *)CCPname, CCPaddr)) {
					_puts("Unable to load the CCP.\r\nCPU halted.\r\n");
					break;
				}
				Z80reset();
				SET_LOW_REGISTER(BC, _RamRead(0x0004));
				PC = CCPaddr;
				Z80run();
				if (Status == CBOOT) {
					break;
				}
			}
		} else {
			_puts("Unable to load the CCP.\r\nCPU halted.\r\n");
		}
	} else {
		_puts("Unable to initialize SD card.\r\nCPU halted.\r\n");
	}
}

void loop(void) {
	digitalWrite(LED, HIGH^LEDinv);
	delay(DELAY);
	digitalWrite(LED, LOW^LEDinv);
	delay(DELAY);
	digitalWrite(LED, HIGH^LEDinv);
	delay(DELAY);
	digitalWrite(LED, LOW^LEDinv);
	delay(DELAY * 4);
}

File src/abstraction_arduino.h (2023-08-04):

#ifndef ABSTRACT_H
#define ABSTRACT_H

#include <TimeLib.h>

#ifdef PROFILE
#define printf(a, b) TERMINALPORT.println(b)
#endif

#define HostOS 0x04

/* Memory abstraction functions */
/*===============================================================================*/
bool _RamLoad(char* filename, uint16 address) {
	File f;
	bool result = false;

	if (f = SD.open(filename, FILE_READ)) {
		while (f.available())
			_RamWrite(address++, f.read());
		f.close();
		result = true;
	}
	return(result);
}

/* Filesystem (disk) abstraction fuctions */
/*===============================================================================*/
File rootdir, userdir;
#define FOLDERCHAR '/'

typedef struct {
	uint8 dr;
	uint8 fn[8];
	uint8 tp[3];
	uint8 ex, s1, s2, rc;
	uint8 al[16];
	uint8 cr, r0, r1, r2;
} CPM_FCB;

typedef struct {
	uint8 dr;
	uint8 fn[8];
	uint8 tp[3];
	uint8 ex, s1, s2, rc;
	uint8 al[16];
} CPM_DIRENTRY;

static DirFat_t	fileDirEntry;

File _sys_fopen_w(uint8* filename) {
	return(SD.open((char*)filename, O_CREAT | O_WRITE));
}

int _sys_fputc(uint8 ch, File& f) {
	return(f.write(ch));
}

void _sys_fflush(File& f) {
	f.flush();
}

void _sys_fclose(File& f) {
	f.close();
}

int _sys_select(uint8* disk) {
	uint8 result = FALSE;
	File f;

	digitalWrite(LED, HIGH ^ LEDinv);
	if (f = SD.open((char*)disk, O_READ)) {
		if (f.isDirectory())
			result = TRUE;
		f.close();
	}
	digitalWrite(LED, LOW ^ LEDinv);
	return(result);
}

uint16 _sys_setfileattributes(uint8* filename, uint16 fcbaddr) {
	CPM_FCB *F = (CPM_FCB*)_RamSysAddr(fcbaddr);
	uint16 result = 0xFF;
	File f;

	digitalWrite(LED, HIGH ^ LEDinv);
	if ((f = SD.open((char*)filename, O_RDONLY))) {
		f.makeHidden(F->fn[1] & 0x80);
		f.makeReadOnly(F->tp[0] & 0x80);
		f.makeSystem(F->tp[1] & 0x80);
		f.makeArchive(F->tp[2] & 0x80);
		f.close();
		result = 0x00;
	}
	digitalWrite(LED, LOW ^ LEDinv);
	return result;

}

uint8 bin2bcd(uint8 bin) {
	return (bin / 10) * 16 + (bin % 10);
}

uint8 bcd2bin(uint8 bcd) {
	return (bcd / 16) * 10 + (bcd % 16);
}

uint16 bytes2uint16(uint8* bytes) {
	return bytes[0] | (bytes[1] << 8);
}
uint16 _sys_getfiletimestamp(uint8* filename) {
	uint16 result = 0xFF;
	File f;
	uint16 dt;
	
	digitalWrite(LED, HIGH ^ LEDinv);
	f = SD.open((char*)filename, O_READ);
	if (f) {
		f.dirEntry(&fileDirEntry);
		f.close();

		dt = bytes2uint16(fileDirEntry.createDate);
		_RamWrite(dmaAddr +  0, bin2bcd(FS_YEAR(dt) % 100));
		_RamWrite(dmaAddr +  1, bin2bcd(FS_MONTH(dt)));
		_RamWrite(dmaAddr +  2, bin2bcd(FS_DAY(dt)));
		dt = bytes2uint16(fileDirEntry.createTime);
		_RamWrite(dmaAddr +  3, bin2bcd(FS_HOUR(dt)));
		_RamWrite(dmaAddr +  4, bin2bcd(FS_MINUTE(dt)));

		dt = bytes2uint16(fileDirEntry.accessDate);
		_RamWrite(dmaAddr +  5, bin2bcd(FS_YEAR(dt) % 100));
		_RamWrite(dmaAddr +  6, bin2bcd(FS_MONTH(dt)));
		_RamWrite(dmaAddr +  7, bin2bcd(FS_DAY(dt)));
		_RamWrite(dmaAddr +  8, 0);	// no last access time, only date
		_RamWrite(dmaAddr +  9, 0);

		dt = bytes2uint16(fileDirEntry.modifyDate);
		_RamWrite(dmaAddr + 10, bin2bcd(FS_YEAR(dt) % 100));
		_RamWrite(dmaAddr + 11, bin2bcd(FS_MONTH(dt)));
		_RamWrite(dmaAddr + 12, bin2bcd(FS_DAY(dt)));
		dt = bytes2uint16(fileDirEntry.modifyTime);
		_RamWrite(dmaAddr + 13, bin2bcd(FS_HOUR(dt)));
		_RamWrite(dmaAddr + 14, bin2bcd(FS_MINUTE(dt)));

		result = 1;
	}
	digitalWrite(LED, LOW ^ LEDinv);
	return result;
}

uint16 _sys_setfiletimetamp(uint8* filename) {
	uint16 result = 0xFF;
	File f;

	digitalWrite(LED, HIGH ^ LEDinv);
	if ((f = SD.open((char*)filename, O_RDONLY))) {
		uint16 year;
		uint8 month, day, hour, minute;
		year = bcd2bin(_RamRead(dmaAddr + 0));
		if (year>77) {
			year += 1900;
		} else {
			year += 2000;
		}
		month = bcd2bin(_RamRead(dmaAddr + 1));
		day = bcd2bin(_RamRead(dmaAddr + 2));
		hour = bcd2bin(_RamRead(dmaAddr + 3));
		minute = bcd2bin(_RamRead(dmaAddr + 4));
		f.timestamp(T_CREATE, year, month, day, hour, minute, 0);

		year = bcd2bin(_RamRead(dmaAddr + 5));
		if (year>77) {
			year += 1900;
		} else {
			year += 2000;
		}
		month = bcd2bin(_RamRead(dmaAddr + 6));
		day = bcd2bin(_RamRead(dmaAddr + 7));
		f.timestamp(T_ACCESS, year, month, day, 0, 0, 0);

		year = bcd2bin(_RamRead(dmaAddr + 10));
		if (year>77) {
			year += 1900;
		} else {
			year += 2000;
		}
		month = bcd2bin(_RamRead(dmaAddr + 11));
		day = bcd2bin(_RamRead(dmaAddr + 12));
		hour = bcd2bin(_RamRead(dmaAddr + 13));
		minute = bcd2bin(_RamRead(dmaAddr + 14));
		f.timestamp(T_WRITE, year, month, day, hour, minute, 0);
		f.close();
		result = 0x01;
	}
	digitalWrite(LED, LOW ^ LEDinv);
	return result;
}

long _sys_filesize(uint8* filename) {
	long l = -1;
	File f;

	digitalWrite(LED, HIGH ^ LEDinv);
	if (f = SD.open((char*)filename, O_RDONLY)) {
		l = f.size();
		f.close();
	}
	digitalWrite(LED, LOW ^ LEDinv);
	return(l);
}

int _sys_openfile(uint8* filename, CPM_FCB* F) {
	File f;
	int result = 0;

	digitalWrite(LED, HIGH ^ LEDinv);
	f = SD.open((char*)filename, O_READ);
	if (f) {
		f.dirEntry(&fileDirEntry);
		f.close();
		F->s1 = fromhex(filename[2]) | 0x80;
		result = 1;
	}
	digitalWrite(LED, LOW ^ LEDinv);
	return(result);
}

int _sys_openpublicfile(uint8* filename, CPM_FCB* F) {
	File f;
	int result = 0;
	uint8 origUserCode = filename[2];
	
	digitalWrite(LED, HIGH ^ LEDinv);
	for( uint8 i = 0; i < 16; ++i) {
		filename[2] = tohex(i);
		f = SD.open((char*)filename, O_READ);
		if (f) {
			f.dirEntry(&fileDirEntry);
			f.close();
			if (fileDirEntry.attributes & FAT_ATTRIB_HIDDEN) {
				F->s1 = fromhex(filename[2]) | 0x80;
				F->fn[6] |= 0x80;	// indicates public file opened to caller
				result = 1;
				break;
			}
		}
	}
	filename[2] = origUserCode;
	digitalWrite(LED, LOW ^ LEDinv);
	return(result);
}

int _sys_closefile(uint8* filename, CPM_FCB* F) {
	File f;
	int result = 0;

	if (!(F->s2 & 0x80)) {	// file is modified
		f = SD.open((char*)filename, O_READ);
		if (f) {
			time_t rightNow = Teensy3Clock.get();
			uint16 yr = year(rightNow);
			uint8 mon = month(rightNow);
			uint8 dy = day(rightNow);
			uint8 hr = hour(rightNow);
			uint8 min = minute(rightNow);
			f.timestamp(T_WRITE, yr, mon, dy, hr, min, 0);
			f.makeArchive(false);
			f.close();
			result = 1;
		}
	} else {
		result = 1;	// close is a formality for unmodified files
	}
	digitalWrite(LED, LOW ^ LEDinv);
	return result;
}
int _sys_makefile(uint8* filename) {
	File f;
	int result = 0;

	digitalWrite(LED, HIGH ^ LEDinv);
	f = SD.open((char*)filename, O_CREAT | O_WRITE);
	if (f) {
		time_t rightNow = Teensy3Clock.get();
		uint16 yr = year(rightNow);
		uint8 mon = month(rightNow);
		uint8 dy = day(rightNow);
		uint8 hr = hour(rightNow);
		uint8 min = minute(rightNow);
		f.timestamp(T_CREATE, yr, mon, dy, hr, min, 0);
		f.close();
		result = 1;
	}
	digitalWrite(LED, LOW ^ LEDinv);
	return(result);
}

int _sys_deletefile(uint8* filename) {
	int result;
	digitalWrite(LED, HIGH ^ LEDinv);
	result = SD.remove((char*)filename);
	digitalWrite(LED, LOW ^ LEDinv);
	return(result);
}
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

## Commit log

2020-06-24 Added kicad files
    [TeensyBoardZ80.sch]
2020-06-24 Adding COM & HLP files to disk image
    [ZCNFG24.CFG, ZEX.CFG, ZF11.CFG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]
2020-06-24 Added schematic image
2020-06-24 Correct schematic image link
2020-06-24 Removed a superfluous file
    [TeensyBoard_VESA_mount_sides.stl]
2020-06-24 Added the STL file for the VESA mount base
    [TeensyBoard_VESA_mount_base.stl]
2020-07-05 Updated README.md to current status.
2020-07-22 Added missing PCB files
    [TeensyBoardZ80.kicad_pcb]
2020-07-23 Updated ZMP files with new version compiled with Hi Tech C v3.09 from http://github.com/mecparts/zmp
    [ZMP.CFG]
2020-07-26 Updated ZMP to latest version.
    [ZMP.CFG]
2020-08-03 1. Added .gitignore. 2. First cut at request/response GSX calls.
2020-08-11 Patched RTS lockout on baud rate change When dialing a number in ZMP, if I aborted the dial once every so often the RTS line would go inactive and stay that way. It could only be fixed by doing a reb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
    [abstraction_arduino.h]
2020-10-17 Added P2DOS timestamp to dir buffer returned by find first/next Though ZSDOS included ZXD.COM, ZXD didn't use the ZSDOS calls to get the file's timestamp, instead it went to the data in the directory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
    [ZXD.CFG]
2020-10-20 BIOS SELDSK call now returns a sensible DPH Previously, this call always returned a 0 in HL, signalling that the drive did not exist. ZCPR3's FF.COM used this call to figure out whether a drive exist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
    [globals.h]
2020-10-26 A quick hack to make F1 and F2 type the current date and time Ugly code getting uglier but hey, it works.
2020-11-07 Added source code of latest Teensy Board/Z80 ZMP overlay.
2020-11-07 Removed ESC doubling in 8 bit input mode Now that I've been able to recompile ZMP, I was able to modify it to allow ANSI cursor sequences from the keyboard to pass thru (by checking to see if there w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
    [abstraction_arduino.h]
2020-11-23 Expanded I/O byte support Added support for the USB serial port as physical devices UC1, UR1, UP1 (user console 1, user reader 1, user punch 1). Also added support for the logical device BAT (RDR in,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
2021-06-10 Moved SO/SI check from _putcrt to _putcon so that 8 bit output flag would be honoured for all logical console devices, not just the physical CRT device.
2021-06-10 Added a lock bit to the NovaDos flags byte so that ZMP would have a mechanism to lock 8 bit output on for the duration it was running, and remote systems (I'm looking at you, Particles! BBS) wouldn't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
    [globals.h]
2021-09-20 1. Moved serial port initialisation before 3 second startup wait. 2. Changed TTY startup baud from 1200 to 9600. 3. Initialised MSPEED variable. 4. Routed CTS signal to a spare input pin so I could r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
    [TeensyBoardZ80.ino, abstraction_arduino.h]
2021-10-07 Changed ZCPR3 clear & home to <ESC>[H<ESC>[J for PuTTY
2023-08-04 When RTS/CTS flow control is turned off, disable the CTS pin.
